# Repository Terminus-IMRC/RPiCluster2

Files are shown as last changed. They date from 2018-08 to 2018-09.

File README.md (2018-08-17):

# RPiCluster2

Yet another Raspberry Pi cluster, which can **chain up to 1+32 Raspberry
Pi's**!!!

Diagram

The Pi on the Motherboard (master) is always turned on, while the other Pi's
(slaves) are turned on/off by the master via I2C.  The master can choose a slave
to communicate with over UART.

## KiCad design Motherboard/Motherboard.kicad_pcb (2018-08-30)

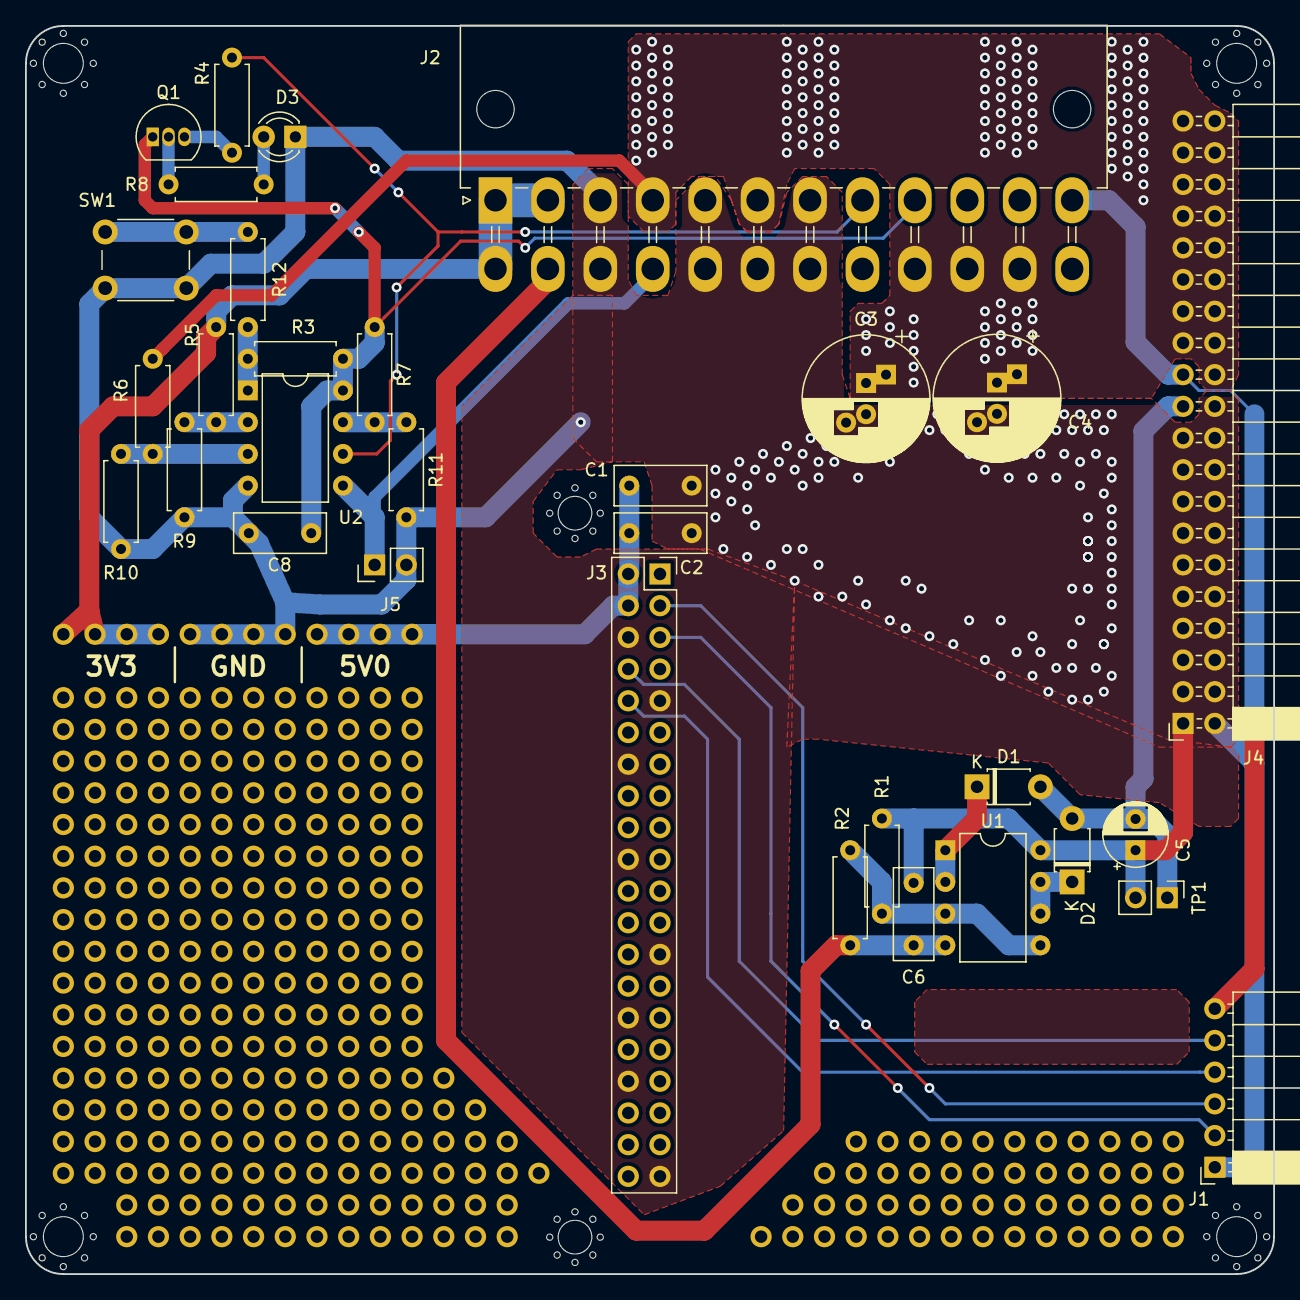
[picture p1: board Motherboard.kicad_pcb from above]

Board: 2 copper layers, 100.0 x 100.0 mm, 32 parts (0 on the bottom side), 23 nets.

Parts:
C1, C2, C6, C8: 10u; C_Rect_L7.2mm_W3.0mm_P5.00mm_FKS2_FKP2_MKS2_MKP2
C3, C4: 470u; CP_Radial_D10.0mm_P2.50mm_P5.00mm
C5: 10u; CP_Radial_D5.0mm_P2.50mm
D1, D2: 0V5; D_T-1_P5.08mm_Horizontal
D3: LED_power_down; LED_D3.0mm
J1: Signal_socket; PinSocket_1x06_P2.54mm_Horizontal
J2: ATX_power; Molex_Mini-Fit_Jr_5569-24A2_2x12_P4.20mm_Horizontal
J3: RPi_server; PinSocket_2x20_P2.54mm_Vertical
J4: Power_socket; PinSocket_2x20_P2.54mm_Horizontal
J5: Test_~PS_ON~; PinHeader_1x02_P2.54mm_Vertical
Q1: 2SA1015; TO-92_Inline
R1: 2k; R_Axial_DIN0207_L6.3mm_D2.5mm_P7.62mm_Horizontal
R2, R8, R12: 10k; R_Axial_DIN0207_L6.3mm_D2.5mm_P7.62mm_Horizontal
R3: 47k; R_Axial_DIN0207_L6.3mm_D2.5mm_P7.62mm_Horizontal
R4: 1k; R_Axial_DIN0207_L6.3mm_D2.5mm_P7.62mm_Horizontal
R5: 6k8±5%; R_Axial_DIN0207_L6.3mm_D2.5mm_P7.62mm_Horizontal
R6, R7: 3k3±5%; R_Axial_DIN0207_L6.3mm_D2.5mm_P7.62mm_Horizontal
R9, R10, R11: 10k±1%; R_Axial_DIN0207_L6.3mm_D2.5mm_P7.62mm_Horizontal
SW1: Reset; SW_PUSH_6mm
TP1: Test_VEE; PinHeader_1x02_P2.54mm_Vertical
U1: LM358; DIP-8_W7.62mm
U2: ATtiny13A-PU; DIP-8_W7.62mm

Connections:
+3V3: J1.6, J2.1, J2.2, J2.12, J2.13, J4.23, R5.1
+5V: C1.2, C2.2, C3.1, C4.1, J2.4, J2.6, J2.21, J2.22, J2.23, J3.2, J3.4, J4.24, J4.25, J4.26, J4.27, J4.28, J4.29, J4.30, J4.31, J4.32, J4.33, J4.34, J4.35, J4.36, J4.37, J4.38, J4.39, J4.40, R6.1
+5VD: C8.2, J2.9, Q1.1, R3.1, R7.1, U2.8
-12V: C6.1, J2.14, R2.2, U1.4
/PWR_OK: J2.8, R4.2, U2.6
/RXD: J1.4, J3.10
/SCL: J1.2, J3.5
/SDA: J1.3, J3.3
/TXD: J1.5, J3.8
/~PS_ON~: J2.16, J5.1, U2.5
GND: C1.1, C2.1, C3.2, C4.2, C5.1, C6.2, C8.1, D3.1, J1.1, J2.3, J2.5, J2.7, J2.15, J2.17, J2.18, J2.19, J2.24, J3.6, J3.9, J3.14, J3.20, J3.25, J3.30, J3.34, J3.39, J4.1, J4.2, J4.3, J4.4, J4.5, J4.6, J4.7, J4.8, J4.9, J4.10, J4.11, J4.12, J4.13, J4.14, J4.15, J4.16, J4.17, J4.18, J4.19, J4.20, J4.22, J5.2, R1.1, R9.2, R10.2, R11.2, SW1.2, TP1.2, U1.8, U2.4
unnamed: D1.1, U1.1, U1.2
unnamed: D2.1, U1.6, U1.7
unnamed: D3.2, R8.2
unnamed: Q1.2, R8.1
unnamed: Q1.3, R4.1
unnamed: R1.2, R2.1, U1.3, U1.5
unnamed: R5.2, R9.1, U2.2
unnamed: R6.2, R10.1, U2.3
unnamed: R7.2, R11.1, U2.7
unnamed: R3.2, R12.1, U2.1
unnamed: R12.2, SW1.1
VEE: C5.2, D1.2, D2.2, J4.21, TP1.1

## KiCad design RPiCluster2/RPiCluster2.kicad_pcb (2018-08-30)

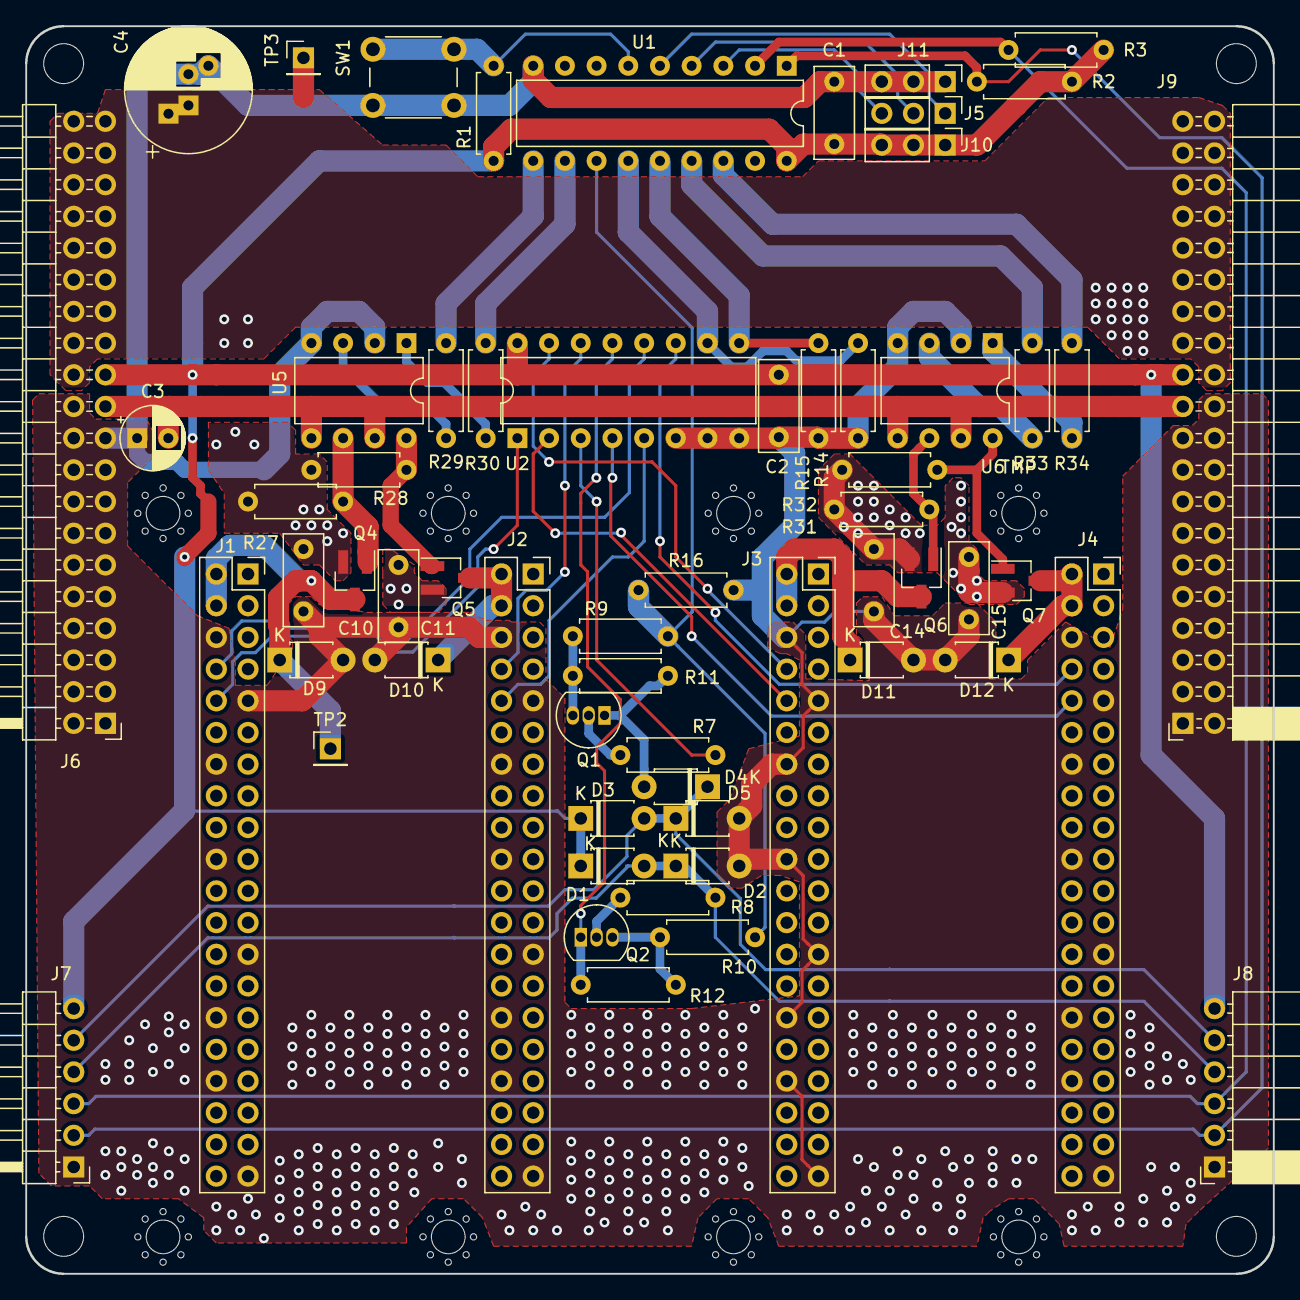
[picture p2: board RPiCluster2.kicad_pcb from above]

Board: 2 copper layers, 100.0 x 100.0 mm, 62 parts (0 on the bottom side), 46 nets.

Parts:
C1, C2, C10, C11, C14, C15: 10u; C_Rect_L7.2mm_W3.0mm_P5.00mm_FKS2_FKP2_MKS2_MKP2
C3: 10u; CP_Radial_D5.0mm_P2.50mm
C4: 470u; CP_Radial_D10.0mm_P2.50mm_P5.00mm
D1, D2, D3, D4, D5: 0V5; D_T-1_P5.08mm_Horizontal
D9, D10, D11, D12: 1V0; D_T-1_P5.08mm_Horizontal
J1: RPi_slave_1; PinSocket_2x20_P2.54mm_Vertical
J2: RPi_slave_2; PinSocket_2x20_P2.54mm_Vertical
J3: RPi_slave_3; PinSocket_2x20_P2.54mm_Vertical
J4: RPi_slave_4; PinSocket_2x20_P2.54mm_Vertical
J5: Addr; PinHeader_1x03_P2.54mm_Vertical
J6: Power_header; PinHeader_2x20_P2.54mm_Horizontal
J7: Signal_header; PinHeader_1x06_P2.54mm_Horizontal
J8: Signal_socket; PinSocket_1x06_P2.54mm_Horizontal
J9: Power_socket; PinSocket_2x20_P2.54mm_Horizontal
J10: Addr_1; PinHeader_1x03_P2.54mm_Vertical
J11: Addr_0; PinHeader_1x03_P2.54mm_Vertical
Q1, Q2: 2SC1815; TO-92_Inline
Q4, Q5, Q6, Q7: IRLML6402; SOT-23_Handsoldering
R1, R14, R15, R16: 47k; R_Axial_DIN0207_L6.3mm_D2.5mm_P7.62mm_Horizontal
R2, R3, R11, R12, R27, R28, R31, R32: 10k; R_Axial_DIN0207_L6.3mm_D2.5mm_P7.62mm_Horizontal
R7, R8, R9, R10, R29, R30, R33, R34: 1k; R_Axial_DIN0207_L6.3mm_D2.5mm_P7.62mm_Horizontal
SW1: Reset; SW_PUSH_6mm
TMP: MountingHole_2.7mm_M2.5
TP2: Test_5V_SLV1; PinHeader_1x01_P2.54mm_Vertical
TP3: Test_5V; PinHeader_1x01_P2.54mm_Vertical
U1: MCP23008; DIP-18_W7.62mm
U2: 4052; DIP-16_W7.62mm
U5, U6: TLP627-2; DIP-8_W7.62mm

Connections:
5V_SLV1: D9.1, J1.2, J1.4, Q4.3, TP2.1
5V_SLV2: D10.1, J2.2, J2.4, Q5.3
5V_SLV3: D11.1, J3.2, J3.4, Q6.3
5V_SLV4: D12.1, J4.2, J4.4, Q7.3
+3V3: C1.2, C2.2, D1.1, D3.1, J6.23, J7.6, J8.6, J9.23, J10.1, J10.2, J10.3, R1.1, R2.1, R3.1, U1.18, U2.16
+5V: C4.1, C10.1, C11.1, C14.1, C15.1, J6.24, J6.25, J6.26, J6.27, J6.28, J6.29, J6.30, J6.31, J6.32, J6.33, J6.34, J6.35, J6.36, J6.37, J6.38, J6.39, J6.40, J9.24, J9.25, J9.26, J9.27, J9.28, J9.29, J9.30, J9.31, J9.32, J9.33, J9.34, J9.35, J9.36, J9.37, J9.38, J9.39, J9.40, Q4.2, Q5.2, Q6.2, Q7.2, R27.1, R28.1, R31.1, R32.1, TP3.1
/MUX_A: R14.1, U1.13, U2.10
/MUX_B: R15.1, U1.14, U2.9
/RXD1: J1.10, U2.1
/RXD2: J2.10, U2.5
/RXD3: J3.10, U2.2
/RXD4: J4.10, U2.4
/RXD_SLV: R7.1, U2.3
/SER_EN: R9.1, R10.1, R16.1, U1.12
/TXD1: J1.8, U2.12
/TXD2: J2.8, U2.14
/TXD3: J3.8, U2.15
/TXD4: J4.8, U2.11
/TXD_SLV: Q2.1, R12.2, U2.13
GND: C1.1, C2.1, C3.1, C4.2, C10.2, C11.2, C14.2, C15.2, D2.2, D5.2, D9.2, D10.2, D11.2, D12.2, J1.6, J1.9, J1.14, J1.20, J1.25, J1.30, J1.34, J1.39, J2.6, J2.9, J2.14, J2.20, J2.25, J2.30, J2.34, J2.39, J3.6, J3.9, J3.14, J3.20, J3.25, J3.30, J3.34, J3.39, J4.6, J4.9, J4.14, J4.20, J4.25, J4.30, J4.34, J4.39, J6.1, J6.2, J6.3, J6.4, J6.5, J6.6, J6.7, J6.8, J6.9, J6.10, J6.11, J6.12, J6.13, J6.14, J6.15, J6.16, J6.17, J6.18, J6.19, J6.20, J6.22, J7.1, J8.1, J9.1, J9.2, J9.3, J9.4, J9.5, J9.6, J9.7, J9.8, J9.9, J9.10, J9.11, J9.12, J9.13, J9.14, J9.15, J9.16, J9.17, J9.18, J9.19, J9.20, J9.22, J11.1, J11.2, J11.3, R14.2, R15.2, R16.2, SW1.2, U1.9, U2.6, U2.7, U2.8, U5.2, U5.4, U6.2, U6.4
unnamed: D4.2, Q1.1, R11.2
unnamed: J5.1, U1.5
unnamed: J5.2, U1.4
unnamed: J5.3, U1.3
unnamed: Q1.2, R7.2
unnamed: Q1.3, R9.2, R11.1
unnamed: Q2.2, R8.2
unnamed: Q2.3, R10.2, R12.1
unnamed: Q4.1, R27.2, U5.6
unnamed: Q5.1, R28.2, U5.8
unnamed: Q6.1, R31.2, U6.6
unnamed: Q7.1, R32.2, U6.8
unnamed: R1.2, SW1.1, U1.6
unnamed: R29.2, U5.3
unnamed: R30.2, U5.1
unnamed: R33.2, U6.3
unnamed: R34.2, U6.1
RXD: D1.2, D2.1, J7.4, J8.4, R8.1
SCL: J7.2, J8.2, R2.2, U1.1
SDA: J7.3, J8.3, R3.2, U1.2
SLV1: R29.1, U1.10
SLV2: R30.1, U1.11
SLV3: R33.1, U1.15
SLV4: R34.1, U1.16
TXD: D3.2, D4.1, D5.1, J7.5, J8.5
VEE: C3.2, J6.21, J9.21, U5.5, U5.7, U6.5, U6.7

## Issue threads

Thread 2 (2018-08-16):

Import the RPiBackCover

Terminus-IMRC, 2018-08-16:
Without knotscream's illustrations...

And fixing the place of the camera mounting holes...

Terminus-IMRC, 2018-08-17:
Done.

Closed 2018-08-17.

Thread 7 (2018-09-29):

extend I2C

paulwratt, 2018-09-29:
32 RPi is kind nice, but still small for a build farm.

You could add the following option (or something similar) to extend it to 128:
https://github.com/fenlogic/multio

Terminus-IMRC, 2018-09-30:
Thank you for the information!  However, because most of the pins between clusters are dedicated to power (`1 * 32 = 32amps!!`), extending GPIO of Raspberry Pi itself is not preferred.

The 32 limitation is because [MCP23008](https://www.microchip.com/wwwproducts/en/MCP23008) (I/O expander) can only change least significant 3 bits (`2**3 * 4 = 32`).  So I'm thinking of having I2C address exchanger, and using both I2C0 and I2C1 of Raspberry Pi.

Terminus-IMRC, 2018-09-30:
Oh, the board you linked uses MCP23017, which is 16-bit version instead of 8-bit, so `2**4 * 8 * 2 = 128`!

paulwratt, 2022-01-19:
I just picked up 2x of these:
https://bmdesigns.com.au/shop/relay128-128-channel-relay-driver/

> This board uses the I2C Based MCP23017, Featuring 8 on board for a total of 128Channels!

Terminus-IMRC, 2022-01-19:
Nice product!
How are you going to supply 5V and 128 Amps, and how do you install the Pi's (GPIO, serial, and wired LAN cables)?
We are suffering from spaghetti cables that prevent us to move them along in our office... 🪢

Terminus-IMRC, 2022-01-19:
Thank you for editing the post, I'd like to have some pictures of your 128 pis running at the same time if you succeed to manage to supply the hugeous power😎

paulwratt, 2022-01-19:
I found a nice (reasonable priced) 850 watt 5v2 power supply, which is about 160A, so that should be enough for at least 128 RPi4's :)

It will take me quite some time to collect them and 52pi towers. I already have a "strange" cabnet layout planed for them mounting each RPi at 45 degree angle to help create convection air flow (maybe tower fans will help too) and eases cable connection and management. The RPi's are mounted on racks sort of like a shoe holder or plate holder from a dishwasher, and these can be stacked above each other. (overall heat management is an issue with tightly packed RPi4's - hence the "strange" cabnet).

I wasn't expecting you to reply so soon, I forgot its 4:00AM here :)

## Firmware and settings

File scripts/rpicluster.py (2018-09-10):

#!/usr/bin/env python3

from math import ceil, log2
from optparse import OptionParser
import Adafruit_GPIO as GPIO
import Adafruit_GPIO.I2C as I2C
import Adafruit_GPIO.MCP230xx as MCP230xx


class RPi_Switcher(object):

    MAX_MCPS = 8
    NUM_RPIS_PER_MCP = 4
    MCP_ADDR_BASE = 0x20

    class MCP(MCP230xx.MCP23008):

        POWER_PINS = [0, 1, 5, 6]
        SERIAL_EN_PIN = 2
        SERIAL_MUX_PINS = [3, 4]

        def print(self, *args):
            print('0x%02x:' % self.address, *args)

        def __init__(self, address, NUM_RPIS_PER_MCP, verbose=False,
                dry_run=False):
            self.address = address
            self.NUM_RPIS_PER_MCP = NUM_RPIS_PER_MCP
            self.verbose = verbose
            self.dry_run = dry_run

            assert(len(self.POWER_PINS) == self.NUM_RPIS_PER_MCP)
            assert(len(self.SERIAL_MUX_PINS) ==
                    int(ceil(log2(self.NUM_RPIS_PER_MCP))))

            if self.dry_run:
                if self.verbose:
                    self.print('Inited with dry-run mode')
                return

            self._device = I2C.get_i2c_device(address)

            self.gpio_bytes = int(ceil(self.NUM_GPIO / 8.0))
            if verbose:
                self.print('gpio_bytes =', self.gpio_bytes)

            old_iodir = self._device.readList(self.IODIR, self.gpio_bytes)
            if verbose:
                self.print('old_iodir =', old_iodir)

            # GPPU: 0=pullup disabled, 1=pullup enabled
            self.gppu = [0x00] * self.gpio_bytes
            self.write_gppu()
            # IODIR is initialized to all 0xff on reset.
            if not all(x == 0x00 for x in old_iodir):
                # Initial run.
                # GPIO: 0=LOW, 1=HIGH
                if verbose:
                    self.print('Initializing GPIO reg to all zero')
                self.gpio = [0x00] * self.gpio_bytes
                self.write_gpio()
            else:
                # Read the current state.
                if verbose:
                    self.print('Using the current value of GPIO reg')
                self.gpio = self._device.readList(self.GPIO, self.gpio_bytes)
                if verbose:
                    self.print('Current GPIO:', self.gpio)
            # IODIR: 0=output, 1=input
            self.iodir = [0x00] * self.gpio_bytes
            self.write_iodir()

        def set_power(self, n, power):
            assert(0 <= n < self.NUM_RPIS_PER_MCP)
            if self.verbose:
                self.print('Setting power of RPi', n, 'to',
                        'on' if power else 'off')
            if not self.dry_run:
                self.output(self.POWER_PINS[n],
                        GPIO.HIGH if power else GPIO.LOW)

        def enable_serial(self, stat):
            if self.verbose:
                self.print('Enabling' if stat else 'Disabling', 'serial')
            if not self.dry_run:
                self.output(self.SERIAL_EN_PIN, GPIO.HIGH if stat else GPIO.LOW)

        def select_serial(self, n):
            assert(0 <= n < self.NUM_RPIS_PER_MCP)
            d = {}
            for i in range(len(self.SERIAL_MUX_PINS)):
                pin = self.SERIAL_MUX_PINS[i]
                if n & (1 << i):
                    d[pin] = GPIO.HIGH
                else:
                    d[pin] = GPIO.LOW
            if self.verbose:
                self.print('select_serial: Writing', d)
            if not self.dry_run:
                self.output_pins(d)

        def get_status_of_pin(self, pin):
            assert(pin < self.gpio_bytes * 8)
            return bool(self.gpio[pin // 8] & (1 << (pin % 8)))

        def get_power(self, n):
            assert(0 <= n < self.NUM_RPIS_PER_MCP)
            return self.get_status_of_pin(self.POWER_PINS[n])

        def get_serial(self):
            if not self.get_status_of_pin(self.SERIAL_EN_PIN):
                return -1
            mux = 0
            for i in range(len(self.SERIAL_MUX_PINS)):
                mux |= self.get_status_of_pin(self.SERIAL_MUX_PINS[i]) << i
            return mux


    def __init__(self, verbose=False, dry_run=False):
        self.verbose = verbose
        self.dry_run = dry_run
        self.mcps = [None for i in range(self.MAX_MCPS)]

    def init_mcp_of_slave(self, n):
        n //= self.NUM_RPIS_PER_MCP
        if self.mcps[n] is not None:
            return self.mcps[n]
        addr = self.MCP_ADDR_BASE + n
        mcp = self.MCP(address=addr, NUM_RPIS_PER_MCP=self.NUM_RPIS_PER_MCP,
                verbose=self.verbose, dry_run=self.dry_run)
        self.mcps[n] = mcp
        return mcp

    def init_all_mcps(self):
        for i in range(self.MAX_MCPS):
            try:
                mcp = self.init_mcp_of_slave(self.NUM_RPIS_PER_MCP * i)
            except OSError:
                pass

    def set_power(self, n, power):
        mcp = self.init_mcp_of_slave(n)
        mcp.set_power(n % self.NUM_RPIS_PER_MCP, power)

    def get_power(self, n):
        try:
            mcp = self.init_mcp_of_slave(n)
        except OSError:
            return False
        return mcp.get_power(n % self.NUM_RPIS_PER_MCP)

    def select_serial(self, n):
        self.init_all_mcps()

        if n >= 0:
            mcp_idx = n // self.NUM_RPIS_PER_MCP
            if self.mcps[mcp_idx] is None:
                raise IOError('MCP device %d ' % mcp_idx +
                        'which corresponds to slave %d is not found' % n)

        for mcp in self.mcps:
            if mcp is not None:
                mcp.enable_serial(False)

        if n >= 0:
            self.mcps[mcp_idx].select_serial(n % self.NUM_RPIS_PER_MCP)
            self.mcps[mcp_idx].enable_serial(True)

    def get_serial(self):
        self.init_all_mcps()
        for i in range(len(self.mcps)):
            mcp = self.mcps[i]
            if mcp is not None:
                stat = mcp.get_serial()
                if stat >= 0:
                    return self.NUM_RPIS_PER_MCP * i + stat
        return -1


def main():
    parser = OptionParser()

    parser.add_option('-v', '--verbose',
            action='store_true', dest='verbose', default=False,
            help='Be verbose (default: no)')
    parser.add_option('-D', '--dry-run',
            action='store_true', dest='dry_run', default=False,
            help='Dry-run mode (default: no)')
    parser.add_option('-d', '--off',
            action='append', type='int', dest='off',
            help='RPi no. to turn off')
    parser.add_option('-e', '--on',
            action='append', type='int', dest='on',
            help='RPi no. to turn on')
    parser.add_option('-s', '--serial',
            action='store', type='int', dest='serial',
            help='RPi no. to connect serial to')
    parser.add_option('-i', '--info',
            action='append', type='str', dest='info',
            help='RPi no. or "s" (serial) to check its status')

    (options, args) = parser.parse_args()
    if len(args) != 0:
        parser.error('Extra arguments specified')

    if options.on is None and \
            options.off is None and \
            options.serial is None and \
            options.info is None:
        parser.print_help()
        return

    sw = RPi_Switcher(verbose=options.verbose, dry_run=options.dry_run)

    if options.off is not None:
        for n in options.off:
            sw.set_power(n, GPIO.LOW)
    if options.on is not None:
        for n in options.on:
            sw.set_power(n, GPIO.HIGH)
    if options.serial is not None:
        sw.select_serial(options.serial)

    if options.info is not None:
        for s in options.info:
            if s == "s":
                print(sw.get_serial())
            else:
                n = int(s, base=0)
                print(int(sw.get_power(n)))


if __name__ == '__main__':
    main()

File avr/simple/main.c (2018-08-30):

/*
 * Target: ATtiny13a
 * avrdude: -U lfuse:w:0x6b:m -U hfuse:w:0xf9:m
 */

#define F_CPU (128e3 / 8)
#include <avr/io.h>
#include <util/delay.h>

int main(void)
{
    uint16_t t;

    /* Set all pins as input.
     */
    DDRB = 0;
    /* PB[2-4] are not connected to anywhere this time, so enable the pull-up
     * resistor on it.
     */
    PORTB = _BV(PORTB2) | _BV(PORTB3) | _BV(PORTB4);

retry:
    DDRB &= ~_BV(DDB0);
    _delay_ms(5000);

    /* PB0 is connected to #PS_ON and it's pulled up by power supply, so let it
     * down.
     */
    DDRB |= _BV(DDB0);

    /* PB1 is connected to PWR_OK.
     */
    for (t = 0; ; ) {
        /* PWR_OK risetime T4<=10ms. */
        _delay_ms(11);
        if (PINB & _BV(PINB1))
            break;
        t += 11;
        if (t > 500)
            /* The power supply takes too long time to boot up, or it's already
             * down.
             */
            goto retry;
    }
    _delay_ms(11);
    /* If the power supply becomes not OK after it becomes OK, turn it off.
     */
    for (; ; )
        if (!(PINB & _BV(PINB1)))
            goto retry;

    /* A deep dive into an infinite loop. */
    return 0;
}

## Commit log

2018-08-14 kicad: Add a legacy Microchip library
2018-08-14 RPiCluster2: Add WIP files
    [RPiCluster2.sch, power.sch, slvdrv.sch]
2018-08-15 RPiCluster2: Changes on power lines
    [RPiCluster2.sch, power.sch, slvdrv.sch]
2018-08-15 RPiCluster2: Pin order changes due to pcb layout limitations
    [RPiCluster2.sch, power.sch, slvdrv.sch]
2018-08-15 RPiCluster2: Reduce testing pins
    [slvdrv.sch]
2018-08-16 RPiCluster2: Add a WIP pcbnew file
    [RPiCluster2.kicad_pcb]
2018-08-16 RPiCluster2: Update
    [RPiCluster2.kicad_pcb, slvdrv.sch]
2018-08-16 RPiCluster2: Pass DRC
    [RPiCluster2.kicad_pcb]
2018-08-16 RPiCluster2: Bump to v0.0.0
    [RPiCluster2.kicad_pcb]
2018-08-16 Motherboard: Add WIP schematics
    [Motherboard.sch]
2018-08-16 Motherboard: Add WIP PCB layout
    [Motherboard.kicad_pcb]
2018-08-16 Motherboard: Update
    [Motherboard.kicad_pcb, Motherboard.sch]
2018-08-17 Motherboard: Use extensions for garber
    [Motherboard.kicad_pcb]
2018-08-17 BackCover2: Add schematics
    [BackCover2.sch]
2018-08-17 BackCover2: Add pcb layout
    [BackCover2.kicad_pcb]
2018-08-17 BackCover2: Update
    [BackCover2.kicad_pcb]
2018-08-17 avr/simple: A simplified power supply controlling program
2018-08-30 RPiCluster2: Fix ambiguous references
    [RPiCluster2.kicad_pcb]
2018-08-30 RPiCluster2: Remove obsolete comment
    [RPiCluster2.sch]
2018-08-30 RPiCluster2: Avoid SER_EN from floating so that the board can be tested without MCP23008
    [RPiCluster2.kicad_pcb, RPiCluster2.sch, power.sch]
2018-08-30 RPiCluster2: Fix swapping slave {TXD,RXD} lines
    [RPiCluster2.kicad_pcb, RPiCluster2.sch]
2018-08-30 Motherboard: Also monitor the PS_OK line
    [Motherboard.kicad_pcb, Motherboard.sch]
2018-08-30 avr/simple: Wait for a sufficient time for power supply to turn on
2018-09-03 rpicluster.py: Fix to import ceil directly from math
    [rpicluster.py]
2018-09-10 scripts/rpicluster.py: Say error if corresponding RPiCluster2 is not found when selecting serial
    [rpicluster.py]
2018-09-10 scripts/rpicluster.py: Add an option to check power status
2018-09-10 scripts/rpicluster.py: Report as powered-off for slave which does not exist
2018-09-10 scripts/rpicluster.py: Print power status as integer
2018-09-10 scripts/rpicluster.sh: Speed-up power status checking

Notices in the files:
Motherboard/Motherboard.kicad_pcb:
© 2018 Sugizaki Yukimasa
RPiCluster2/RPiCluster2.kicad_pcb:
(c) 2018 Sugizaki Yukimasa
